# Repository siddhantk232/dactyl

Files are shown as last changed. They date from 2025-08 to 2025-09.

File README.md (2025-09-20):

# Dactyl 56

This repository contains the ZMK firmware configuration and STL files for my wireless Dactyl 5x6 keyboard build.

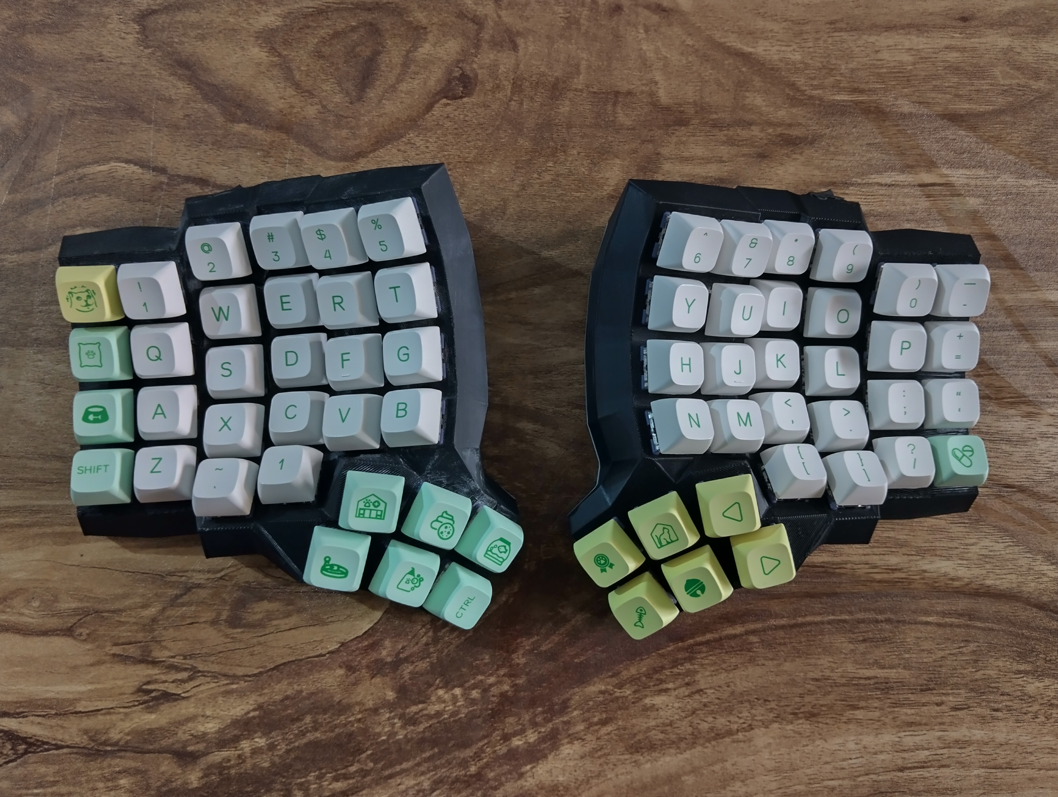
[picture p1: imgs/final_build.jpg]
dactyl 56


## STL files

The STL files are generated using https://ryanis.cool/cosmos/. You can access my configuration using [this link][3dprintconfig].

## ZMK

The keymap defined in [./config/dactyl_56.keymap](./config/dactyl_56.keymap) is outdated since I have shifted to using zmk-studio to be able to change the mapping without re-flashing.

Sadly, zmk-studio does not provide a way to export your config to a file for reproducability. This means I will loose my keymap when I re-flash the firmware. This is not exactly true as explained [in this issue comment][zmk-studio-issue-comment], but I am not aware if it is possible to backup the on board keymap as of writing this.

## Sourcing the hardware

If you are looking to build a similar project and you live in India then the following table might help you.

<table border="1" cellspacing="0" cellpadding="6">
  <tr>
    <th>Name</th>
    <th>Source</th>
    <th>Price (INR)</th>
  </tr>
   <tr>
    <td>3D Prints</td>
    <td><a href="https://www.instagram.com/paws.3d">paws.3d</a></td>
    <td>2500</td>
  </tr>
  <tr>
    <td>SuperMini nRF52840 BLE controller (nice!nano clones)</td>
    <td><a href="https://robokits.co.in/iot-wireless-solutions/iot-internet-of-things/iot-esp-module/supermini-nrf52840-pro-micro-bluetooth-le-ble-controller-arduino-compatible">Robokits</a></td>
    <td>1773</td>
  </tr>
  <tr>
    <td>Switches (Haimu Navy Jade Tactiles)</td>
    <td><a href="https://neomacro.in/products/haimu-navy-jade-tactiles">NeoMacro</a></td>
    <td>1395</td>
  </tr>
  <tr>
    <td>64 × 1N4148 diodes</td>
    <td rowspan="16"><a href="https://makerbazar.in/">MakerBazar</a></td>
    <td rowspan="16">1820</td>
  </tr>
  <tr><td>Hot glue gun</td></tr>
  <tr><td>Female–Female jumper wires</td></tr>
  <tr><td>10 mm Kapton tape</td></tr>
  <tr><td>5 mm copper tape</td></tr>
  <tr><td>Mini breadboard</td></tr>
  <tr><td>Nipper</td></tr>
  <tr><td>Batteries</td></tr>
  <tr><td>Battery protection circuit (<b>not used</b>)</td></tr>
  <tr><td>Soldering iron</td></tr>
  <tr><td>Solder wire</td></tr>
  <tr><td>Soldering Stand and Cleaning Sponge</td></tr>
  <tr><td>Push button switch (SPST, 2-pin)</td></tr>
  <tr><td>18 × M3 × 6 mm flat-head screws</td></tr>
  <tr><td>2 × M3 × 10 mm flat-head screws</td></tr>
  <tr><td>20 × M3 screw inserts</td></tr>
  <tr>
    <td>Rocker switches (2 pcs)</td>
    <td>Locally Sourced</td>
    <td>20</td>
  </tr>
  <tr>
    <td>64 × 1U DSA keycaps (Strange Cat set)</td>
    <td><a href="https://curiositycaps.in/products/strange-cat-104-26-xda-profile-keycap-pbt">CuriosityCaps</a></td>
    <td>2400</td>
  </tr>
  <tr>
    <td colspan="2" style="text-align:right;"><strong>Total</strong></td>
    <td><strong>9908</strong></td>
  </tr>
</table>

## Resources

You can visit the following links if you want to learn more about the build process.

- [The original dactyl project](https://github.com/adereth/dactyl-keyboard). This is great to learn more about the design of the dactyl style of keyboards. I highly recommend watching [the talk](https://www.youtube.com/watch?v=uk3A41U0iO4).
- [Dactyl Manuform build stream on YouTube by Kevin Eckert](https://www.youtube.com/playlist?list=PLJcTwFs4jAY0VnJDXhexZw7X3OIjXQkiY). This is where I got the idea of using copper tape for connecting the columns of the keyboard. The video series features a wired build but most of it applies to the wireless variant as well.
- [This Reddit Post](https://www.reddit.com/r/mkindia/comments/odiql9/dactyl_manuform_5x6_no_imports_budget_build_less/). It shares a few tips for "Looping" the diodes and using a mini breadboard for soldering the microcontroller header pins which I adopted.
- [Dactyl Manuform Repo](https://github.com/abstracthat/dactyl-manuform). The readme contains wiring diagrams that helped me during the actual build process.
- [ZMK Docs](https://zmk.dev/docs) is pretty much the only resource I used to configure the firmware. The project is very well documented.
- [nice!nano v2 pin diagram](https://nicekeyboards.com/docs/nice-nano/pinout-schematic).

[3dprintconfig]: https://ryanis.cool/cosmos/beta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
[zmk-studio-issue-comment]: https://github.com/zmkfirmware/zmk-studio/issues/124#issuecomment-2662519535

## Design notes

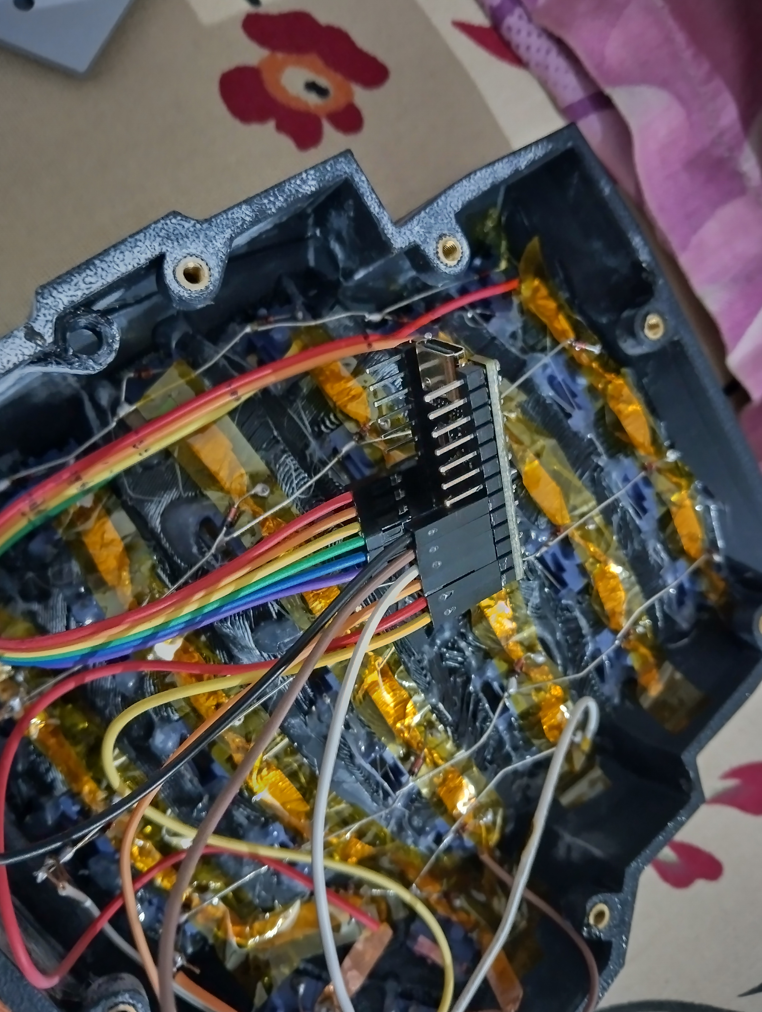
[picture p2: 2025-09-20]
imgs/connection_to_microcontroller.jpg

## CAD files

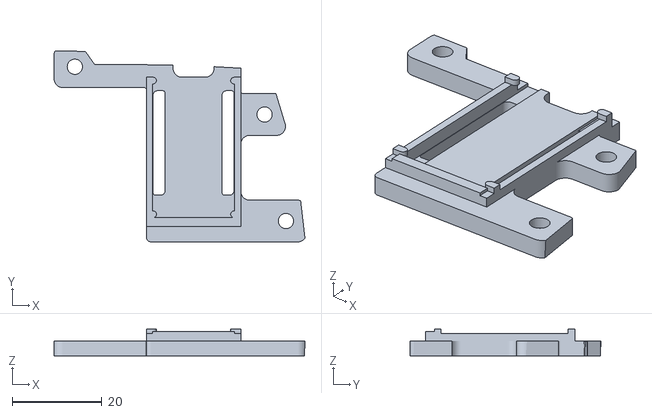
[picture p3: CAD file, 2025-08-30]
stls/dactyl_5x6-holderleft.stl
55.9 x 42.5 x 5.97

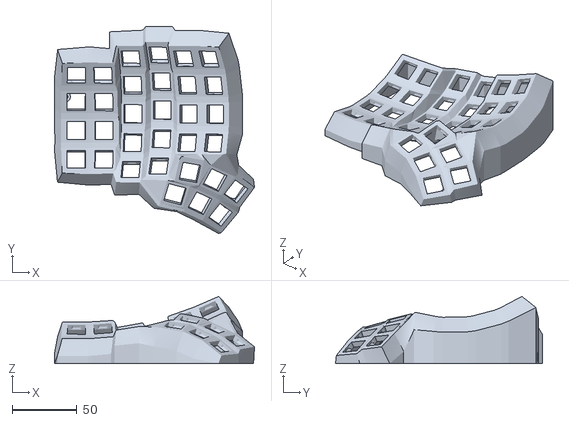
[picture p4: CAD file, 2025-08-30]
stls/dactyl_5x6-caseleft.stl
154.6 x 160.0 x 51.9

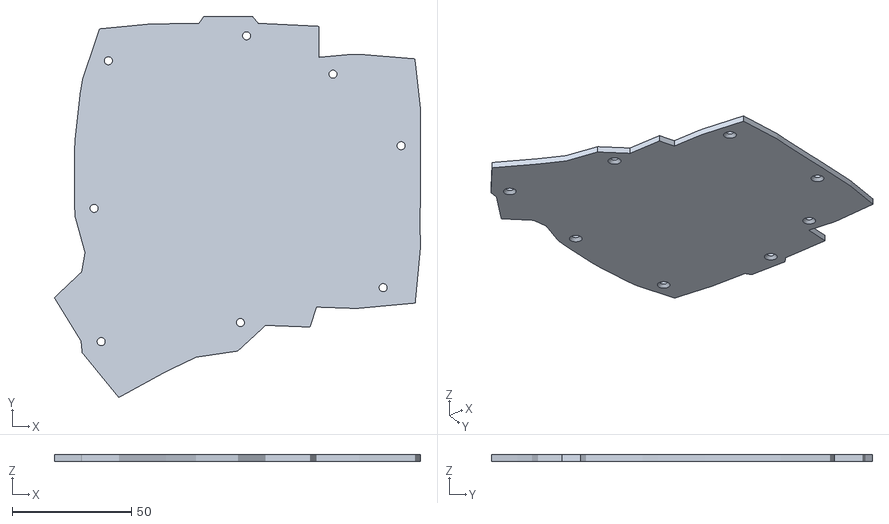
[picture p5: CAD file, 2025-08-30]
stls/dactyl_5x6-plateright.stl
153.9 x 160.0 x 3.00

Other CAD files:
stls/dactyl_5x6-caseright.stl
stls/dactyl_5x6-holderright.stl
stls/dactyl_5x6-plateleft.stl

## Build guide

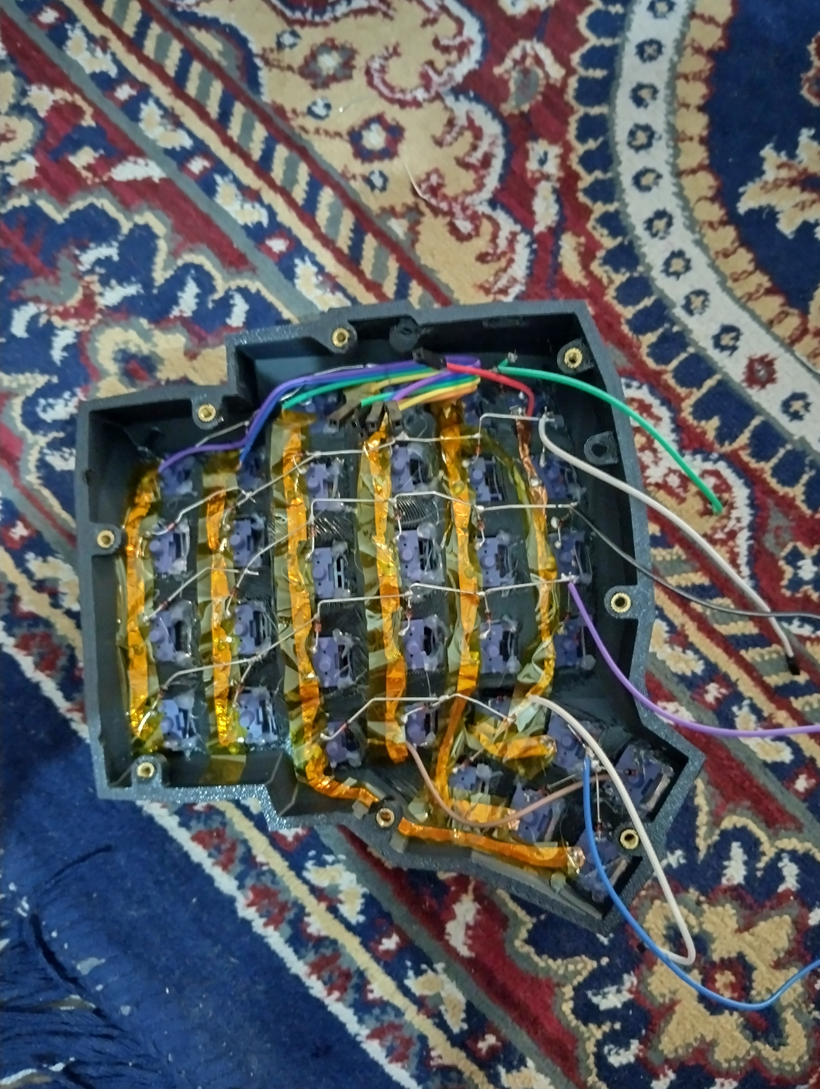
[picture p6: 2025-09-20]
imgs/internal_wiring.jpg

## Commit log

2025-08-29 fix: put boards at the top level
    as referenced from https://github.com/zmkfirmware/unified-zmk-config-template/
2025-08-29 fix: change top row pin for right half
2025-08-30 try nnv2 to see if battery charging works
2025-08-30 add STLs
    [dactyl_5x6-caseleft.stl, dactyl_5x6-caseright.stl, dactyl_5x6-holderleft.stl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]
